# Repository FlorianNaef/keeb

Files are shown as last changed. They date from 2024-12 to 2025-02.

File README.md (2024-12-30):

# keeb

For Kicad to work, you need 
1. The symbols and footprints by [scottokeebs](https://github.com/joe-scotto/scottokeebs/tree/main/Extras/ScottoKicad)
2. The symbols and footprints in this repo. For this you need to set a path to the directory of this repo and add the symbol library and footprints like in 1.

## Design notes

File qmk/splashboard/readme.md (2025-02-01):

# splashboard

splashboard

*A short description of the keyboard/project*

* Keyboard Maintainer: [Florian Naef](https://github.com/FlorianNaef)
* Hardware Supported: Raspberry Pi Pico 2

See the [build environment setup](https://docs.qmk.fm/#/getting_started_build_tools) and the [make instructions](https://docs.qmk.fm/#/getting_started_make_guide) for more information. Brand new to QMK? Start with our [Complete Newbs Guide](https://docs.qmk.fm/#/newbs).

## Bootloader

Enter the bootloader:

* **Physical reset button**: Press the button on the Pico.

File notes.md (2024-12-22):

# Notes

## Powering a Pico from another

If you have two Raspberry Pi Pico WH boards and want to power one from the other using a laptop's USB port, here's how you can do it:

### Step-by-Step Guide:

1. **Power the First Pico:**

   - Connect the first Raspberry Pi Pico WH to your laptop using a USB cable. This will provide power to the first Pico.

2. **Connect the Picos Together:**
   - **VSYS Pin:** Connect the **VSYS pin (pin 39)** of the first Pico to the **VSYS pin (pin 39)** of the second Pico. This will supply power from the first Pico to the second Pico.
   - **Ground Pin:** Connect a **GND pin** (there are multiple GND pins, such as pin 3, pin 8, etc.) from the first Pico to a **GND pin** on the second Pico. This completes the power circuit.

### Wiring Diagram:

Here's a simplified wiring diagram for clarity:

```
First Pico                  Second Pico
----------                  -----------
VSYS (pin 39)  ----->  VSYS (pin 39)
GND (any GND)  ----->  GND (any GND)
```

### Important Considerations:

- **Current Limitation:** Ensure that the total current draw does not exceed the USB port's capability. A standard USB port (5V, 0.5A) can typically handle powering two Pico boards, but if you connect additional peripherals, you may need a powered USB hub or a dedicated power supply.
- **Power Supply Quality:** If you experience instability, consider using a power bank or a more robust power source.

This setup should work for basic projects and running your programs on the second Pico. If you have any specific questions or need further assistance, let me know!

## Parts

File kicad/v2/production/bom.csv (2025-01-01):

Designator | Footprint | Quantity | Value | LCSC Part #
D1, D10, D11, D12, D13, D14, D15, D16, D17, D18, D19, D2, D20, D21, D22, D23, D24, D25, D26, D27, D28, D29, D3, D30, D31, D32, D33, D34, D35, D36, D37, D38, D39, D4, D40, D41, D42, D43, D44, D45, D46, D47, D48, D49, D5, D50, D51, D52, D53, D54, D6, D7, D8, D9 | Diode_DO-35 | 54 | Diode
S1, S10, S11, S12, S13, S14, S15, S16, S17, S18, S19, S2, S20, S21, S22, S23, S24, S25, S26, S27, S28, S29, S3, S30, S31, S32, S33, S34, S35, S36, S37, S38, S39, S4, S40, S41, S42, S43, S44, S45, S46, S47, S48, S49, S5, S50, S51, S52, S53, S54, S6, S7, S8, S9 | Choc_V1_1.00u | 54 | Keyswitch
U1, U2 | Raspberry_Pi_Pico | 2 | Raspberry_Pi_Pico
U3, U5 | Lumberg 1503 29 Klinken-Einbaubuchse | 2 | ~

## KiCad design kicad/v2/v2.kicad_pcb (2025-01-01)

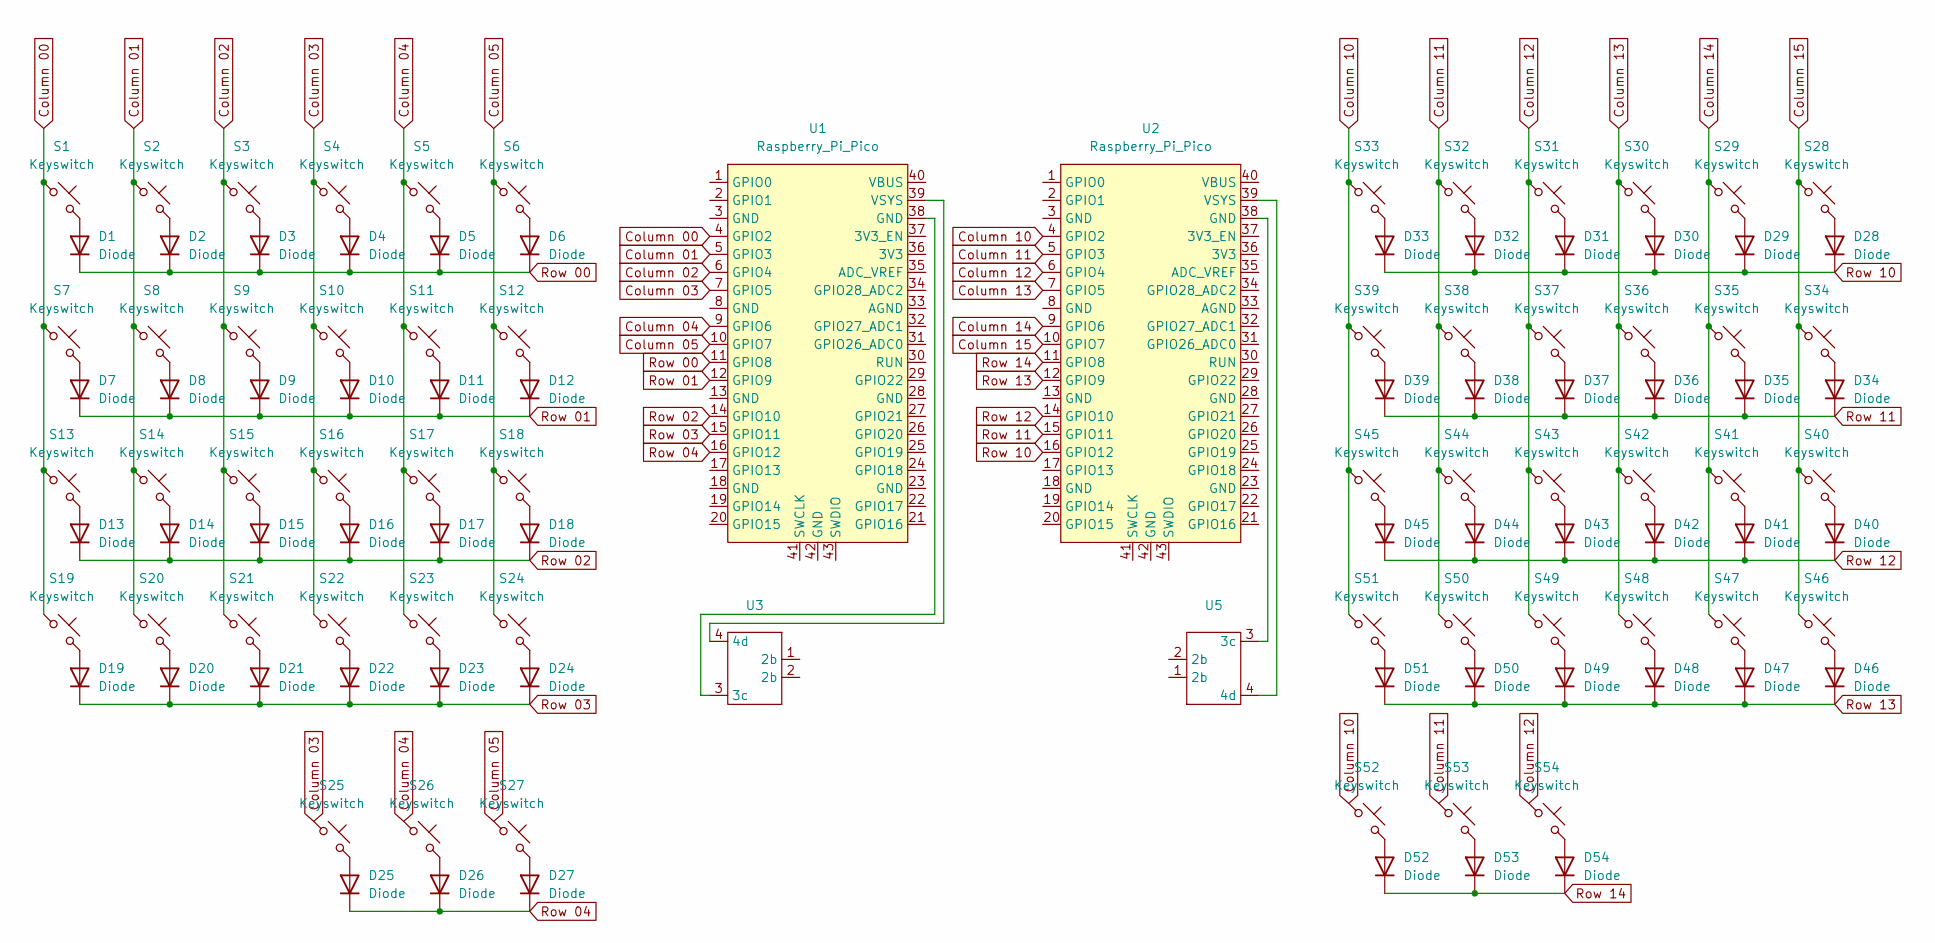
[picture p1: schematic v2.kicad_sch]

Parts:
D1, D2, D3, D4, D5, D6, D7, D8, D9, D10, D11, D12, D13, D14, D15, D16, D17, D18, D19, D20, D21, D22, D23, D24, D25, D26, D27, D28, D29, D30, D31, D32, D33, D34, D35, D36, D37, D38, D39, D40, D41, D42, D43, D44, D45, D46, D47, D48, D49, D50, D51, D52, D53, D54: Diode; Diode_DO-35
S1, S2, S3, S4, S5, S6, S7, S8, S9, S10, S11, S12, S13, S14, S15, S16, S17, S18, S19, S20, S21, S22, S23, S24, S25, S26, S27, S28, S29, S30, S31, S32, S33, S34, S35, S36, S37, S38, S39, S40, S41, S42, S43, S44, S45, S46, S47, S48, S49, S50, S51, S52, S53, S54: Keyswitch; Choc_V1_1.00u
U1, U2: Raspberry_Pi_Pico
U3, U5: Lumberg 1503 29 Klinken-Einbaubuchse

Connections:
Column 00: S1.1, S7.1, S13.1, S19.1, U1.4 (GPIO2)
Column 01: S2.1, S8.1, S14.1, S20.1, U1.5 (GPIO3)
Column 02: S3.1, S9.1, S15.1, S21.1, U1.6 (GPIO4)
Column 03: S4.1, S10.1, S16.1, S22.1, S25.1, U1.7 (GPIO5)
Column 04: S5.1, S11.1, S17.1, S23.1, S26.1, U1.9 (GPIO6)
Column 05: S6.1, S12.1, S18.1, S24.1, S27.1, U1.10 (GPIO7)
Column 10: S33.1, S39.1, S45.1, S51.1, S52.1, U2.4 (GPIO2)
Column 11: S32.1, S38.1, S44.1, S50.1, S53.1, U2.5 (GPIO3)
Column 12: S31.1, S37.1, S43.1, S49.1, S54.1, U2.6 (GPIO4)
Column 13: S30.1, S36.1, S42.1, S48.1, U2.7 (GPIO5)
Column 14: S29.1, S35.1, S41.1, S47.1, U2.9 (GPIO6)
Column 15: S28.1, S34.1, S40.1, S46.1, U2.10 (GPIO7)
unnamed: D1.2 (A), S1.2
unnamed: D2.2 (A), S2.2
unnamed: D3.2 (A), S3.2
unnamed: D4.2 (A), S4.2
unnamed: D5.2 (A), S5.2
unnamed: D6.2 (A), S6.2
unnamed: D7.2 (A), S7.2
unnamed: D8.2 (A), S8.2
unnamed: D9.2 (A), S9.2
unnamed: D10.2 (A), S10.2
unnamed: D11.2 (A), S11.2
unnamed: D12.2 (A), S12.2
unnamed: D13.2 (A), S13.2
unnamed: D14.2 (A), S14.2
unnamed: D15.2 (A), S15.2
unnamed: D16.2 (A), S16.2
unnamed: D17.2 (A), S17.2
unnamed: D18.2 (A), S18.2
unnamed: D19.2 (A), S19.2
unnamed: D20.2 (A), S20.2
unnamed: D21.2 (A), S21.2
unnamed: D22.2 (A), S22.2
unnamed: D23.2 (A), S23.2
unnamed: D24.2 (A), S24.2
unnamed: D25.2 (A), S25.2
unnamed: D26.2 (A), S26.2
unnamed: D27.2 (A), S27.2
unnamed: D28.2 (A), S28.2
unnamed: D29.2 (A), S29.2
unnamed: D30.2 (A), S30.2
unnamed: D31.2 (A), S31.2
unnamed: D32.2 (A), S32.2
unnamed: D33.2 (A), S33.2
unnamed: D34.2 (A), S34.2
unnamed: D35.2 (A), S35.2
unnamed: D36.2 (A), S36.2
unnamed: D37.2 (A), S37.2
unnamed: D38.2 (A), S38.2
unnamed: D39.2 (A), S39.2
unnamed: D40.2 (A), S40.2
unnamed: D41.2 (A), S41.2
unnamed: D42.2 (A), S42.2
unnamed: D43.2 (A), S43.2
unnamed: D44.2 (A), S44.2
unnamed: D45.2 (A), S45.2
unnamed: D46.2 (A), S46.2
unnamed: D47.2 (A), S47.2
unnamed: D48.2 (A), S48.2
unnamed: D49.2 (A), S49.2
unnamed: D50.2 (A), S50.2
unnamed: D51.2 (A), S51.2
unnamed: D52.2 (A), S52.2
unnamed: D53.2 (A), S53.2
unnamed: D54.2 (A), S54.2
unnamed: U1.39 (VSYS), U3.4 (4d)
unnamed: U2.39 (VSYS), U5.4 (4d)
unnamed: U1.38 (GND), U3.3 (3c)
unnamed: U2.38 (GND), U5.3 (3c)
Row 00: D1.1 (K), D2.1 (K), D3.1 (K), D4.1 (K), D5.1 (K), D6.1 (K), U1.11 (GPIO8)
Row 01: D7.1 (K), D8.1 (K), D9.1 (K), D10.1 (K), D11.1 (K), D12.1 (K), U1.12 (GPIO9)
Row 02: D13.1 (K), D14.1 (K), D15.1 (K), D16.1 (K), D17.1 (K), D18.1 (K), U1.14 (GPIO10)
Row 03: D19.1 (K), D20.1 (K), D21.1 (K), D22.1 (K), D23.1 (K), D24.1 (K), U1.15 (GPIO11)
Row 04: D25.1 (K), D26.1 (K), D27.1 (K), U1.16 (GPIO12)
Row 10: D28.1 (K), D29.1 (K), D30.1 (K), D31.1 (K), D32.1 (K), D33.1 (K), U2.16 (GPIO12)
Row 11: D34.1 (K), D35.1 (K), D36.1 (K), D37.1 (K), D38.1 (K), D39.1 (K), U2.15 (GPIO11)
Row 12: D40.1 (K), D41.1 (K), D42.1 (K), D43.1 (K), D44.1 (K), D45.1 (K), U2.14 (GPIO10)
Row 13: D46.1 (K), D47.1 (K), D48.1 (K), D49.1 (K), D50.1 (K), D51.1 (K), U2.12 (GPIO9)
Row 14: D52.1 (K), D53.1 (K), D54.1 (K), U2.11 (GPIO8)

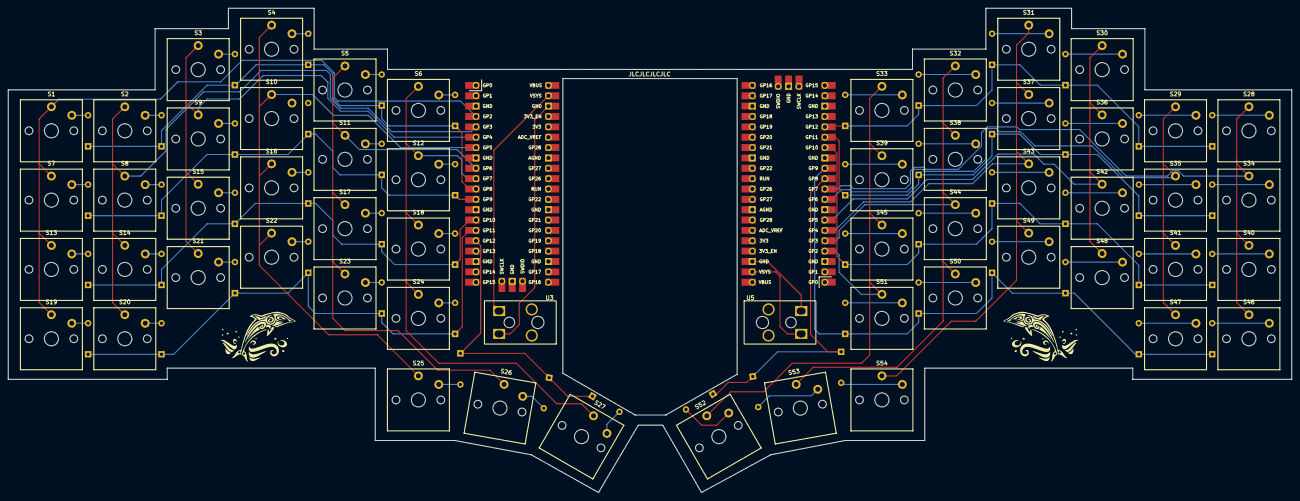
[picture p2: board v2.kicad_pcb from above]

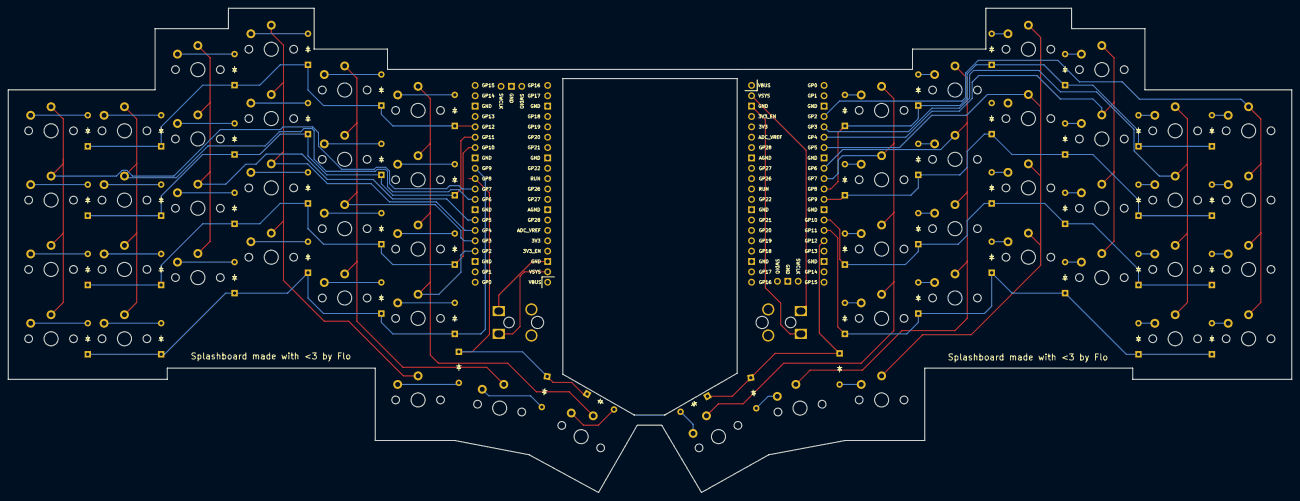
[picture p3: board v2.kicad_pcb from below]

Board: 2 copper layers, 314.8 x 118.8 mm, 112 parts (54 on the bottom side), 80 nets.

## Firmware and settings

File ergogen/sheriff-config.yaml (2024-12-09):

units:
  kx: U
  ky: U
  padding: 4
  px: kx+padding
  py: ky+padding
  sx: 0.5px
  sy: 0.5py
  mcu_height: 34
  mcu_width: 18
  # distance keys to mcu
  mcu_padding: 1.5
  scrollwheel_width: 18
  scrollwheel_height: 16
  screw_diameter: 4
  screw_hole: 2
  switchplate_switch_cutout: 14
  switchplate_switch_base_cutout: 16
  switchplate_scrollwheel_cutout_x: 18
  switchplate_scrollwheel_cutout_y: 16
  switchplate_screw_diameter: 3.3
  switchplate_screw_hole: 2.2
  screen_screw_diameter: 4
  screen_screw_hole: 2.2

  usb_width: 10
  usb_height: 20
  usb_fillet: 2

  trrs_width: 6
  trrs_height: 20
  trrs_radius: 2.5

  thumb_radius: 60
  thumb_cluster_angle: 26
  thumb_cluster_start_angle: 74
  thumb_cluster_rotation: -80

  pcb_thickness: 1.6

  # ---------------------------------------------- The parameters below can be changed. The names are pretty much self-explanatory ----------------------------------------------

  case_screw_insert_diameter: 3
  case_standoff_diameter: 6

  case_base_thickness: 3
  case_support_height: 2
  case_wall_thickness: 2
  case_wall_height: 5.6
  case_wall_margin: 0.5     # Margin between the wall and the board

  footpad_diameter: 11
  footpad_slot_depth: 0.4

  tenting_mount_hole_diameter: 5
  tenting_mount_perimeter_diameter: 12
  tenting_mount_thickness: 4
  tenting_mount_lift_height: case_base_thickness + case_support_height + case_wall_height - tenting_mount_thickness

points:
  zones:
    #   ----------------------- Key switches -----------------------

    matrix:

      anchor.shift: [50, -150]
      key:
        tags: [switch]
        padding: 1ky
        spread: 1kx
        height: 1ky
        width: 1kx
      columns:
        outer2:
          rows:
            mod:
              skip: true
            bottom:
              row_net: row2
            home:
              row_net: row1
            top:
              row_net: row0
              tags: [switch_high]
            num:
              skip: true
          key.column_net: col0
        outer1:
          # rows.mod.skip: true
          rows.num.skip: true
          rows.top.tags: [switch_high]
          key.column_net: col1
        pinky:
          # for pinky(and the two rows above, home position is actually the bottom row, and the "num" row here is an extra row for ring finger)
          rows.top.tags: [switch_high]
          key.column_net: col2
        ring:
          key:
            stagger: 15 - ky
            column_net: col3

        middle:
          key:
            stagger: 4
            column_net: col4

        index:
          key:
            stagger: -7
            column_net: col5
          rows.mod.skip: true
        inner:
          rows.mod.skip: true
          key:
            stagger: -3
            column_net: col6
      rows:
        # Four main rows, one partial row.
        mod:
          row_net: row4
        bottom:
          row_net: row3
        home:
          row_net: row2
        top:
          row_net: row1
        num:
          row_net: row0
          tags: [switch_high]

    thumb_center:
      key.skip: true
      anchor:
        ref: matrix_index_home
        shift: [3, -95]

    thumb_cluster:
      key:
        tags: [switch]
        padding: kx
        spread: ky
        height: 1ky
        width: 1kx
        # rotate: -90
      anchor:
        ref: thumb_center
        orient: thumb_cluster_start_angle - thumb_cluster_angle
        shift: [thumb_radius - 0.5kx, ky]
        rotate: thumb_cluster_rotation
      columns:
        inner:
          rows.high.skip: true
          rows.low:
            row_net: row4
            column_net: col6
          key.rotate: 15
          key.shift: [-2.5, -1]
        home:
          rows.high:
            column_net: col1
            row_net: row0
            shift: [0.1kx, 0]
            width: 1.6kx
          rows.low:
            column_net: col0
            row_net: row4

        outer:
          rows.high.skip: true
          rows.low:
            column_net: col0
            row_net: row3
      rows:
        low:
          tags: [switch]
        high:
          tags: [thumb_switch_high]


   #   ----------------------- Thumb cluster reference points -----------------------
    thumb_outer_ref:
      anchor:
        ref: thumb_center
        orient: thumb_cluster_start_angle - 40
        shift: [thumb_radius, 0]
      columns:
        point.key:
          width: 3
          height: 3

    thumb_home_ref:
      anchor:
        ref: thumb_center
        orient: thumb_cluster_start_angle - 20
        shift: [thumb_radius, 0]
      columns:
        point.key:
          width: 3
          height: 3

    thumb_inner_ref:
      anchor:
        ref: thumb_center
        orient: thumb_cluster_start_angle
        shift: [thumb_radius, 0]
      columns:
        point.key:
          width: 3
          height: 3
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

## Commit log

2024-11-22 add: kicad project
    [keeb.kicad_pcb]
2024-12-08 add: v1 4x4 matrix
    [bom.csv, designators.csv, keeb.kicad_pcb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]
2024-12-09 add: v2
    [v2.kicad_pcb, v2.kicad_sch]
2024-12-22 fix: symetry
    [v2.kicad_pcb]
2024-12-30 add: 3.5mm jacks with very messy wiring
    [v2.kicad_pcb, v2.kicad_sch]
2025-01-01 add: finishing touches
    [bom.csv, designators.csv, positions.csv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]
2025-01-01 fix: make pcb pass dfm check
    [positions.csv, v2.kicad_pcb]
2025-01-01 add: second stability beam
    [v2.kicad_pcb]
